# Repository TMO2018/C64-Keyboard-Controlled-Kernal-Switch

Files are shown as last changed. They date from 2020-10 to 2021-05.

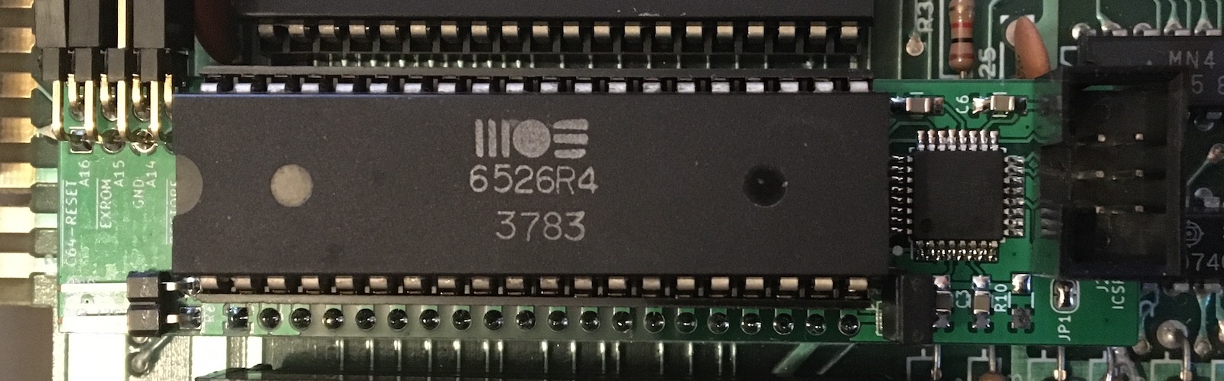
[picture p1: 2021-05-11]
Rev_3_0/pic/IMG_0387.JPG

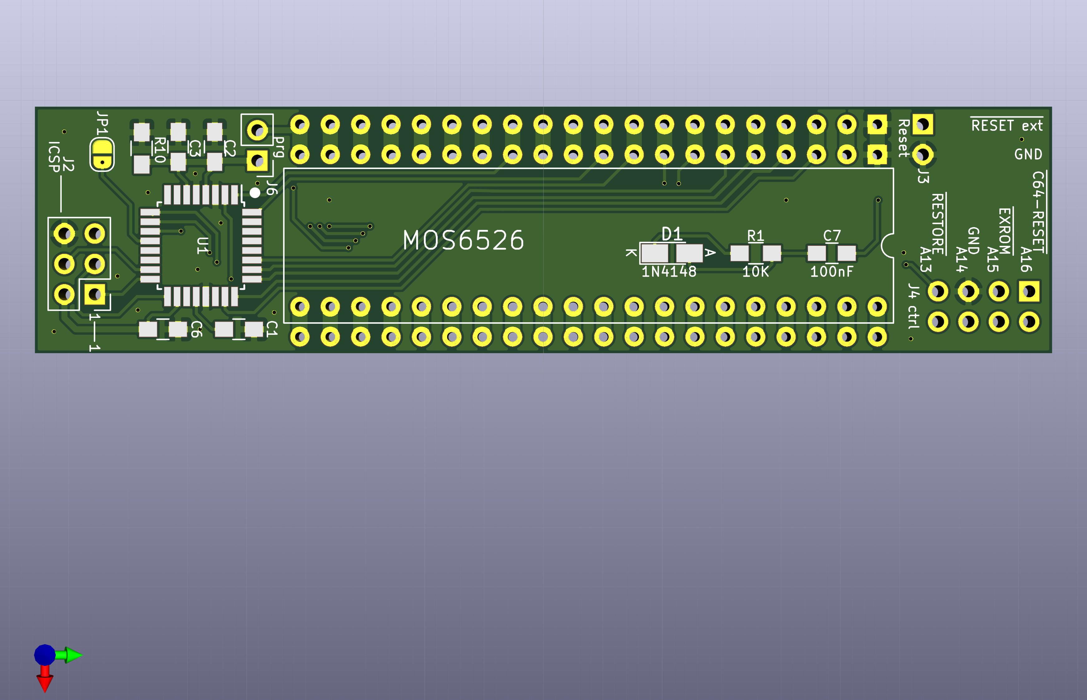
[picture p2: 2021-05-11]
Rev_3_0/pic/top.jpg

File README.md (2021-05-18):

# C64-Keyboard-Controlled-Kernal-Switch for 6526

This project is based on the C64 Keyboard Controlled Kernal Switch Rev. 1.0 from Sven Petersen  (github: svenpetersen1965). For additional informations take a look at Sven Petersens github repository. 

The original kernal switch ist directly connected to the C64 keyboard connector. In my C64 (bread box) with board Assy 250407 the Kernal Switch lies on the fastening screw and other components with the risk of an electrical connection. So I developed an alternative.
The kernal switch 6526 is an intermediate socket for the 6526 on U1.

Advantage:
- better mechanical stability
- SMD soldering pads for hand soldering

Disadvantage:
- additional line for querying the restore button
- if the 6526 is not socketed, it must be unsoldered

Rev 1.0: Design based on Sven Petersens C64 Keyboard Controlled Kernal Switch (ATmega with external clock at 16 MHz), 8 kernals

Rev 2.0: Cost-reduced Design (ATmega with internal clock at 8 MHz), 8 kernals

Rev 3.0: Expansion from 8 to 14 kernals. Based on Rev 2.0.

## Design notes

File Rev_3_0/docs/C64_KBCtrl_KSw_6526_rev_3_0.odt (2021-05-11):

Project Documentation

Commodore C64 – Keyboard Controlled Kernal Switch 6526

Revision: 3.0

Date: 24.04.2021

Cost-reduced variant, 14 kernals


C64 Keyboard Controlled Kernal Switch 6526 Rev. 3.0

General

This project is based on the C64 Keyboard Controlled Kernal Switch Rev. 1.0 from Sven Petersen (github: svenpertersen1965). For additional informations take a look at Sven Petersens github resipository.

The original kernal switch ist directly connected to the C64 keyboard connector. In my C64 (breadbin) with board Assy 250407 the Kernal Switch lies on the fastening screw and other components with the risk of an electrical connection. So I developed an alternative.

The kernal switch 6526 is an intermediate socket for the 6526 on U1.

This is an cost-reduced variant of the C64 Keyboard Controlled Kernal Switch 6526 Rev. 1.0. The ATmega runs with the internal oscillator at 8MHz. Version 3.0 dispenses with the LED and the serial debug interface. For this, the switchover from 8 to 14 kernals is being expanded.

The following components are not required: 1x crystal, 2x ceramic condensator, 4 x resistor, 1x 3 pol connector.

Advantage:

- better mechanical stability

- SMD soldering pads for hand soldering

- fewer components

Disadvantage:

- additional line for querying the restore button

- if the 6526 is not socketed, it must be unsoldered

Connection points:

RESET → Userport pin 3

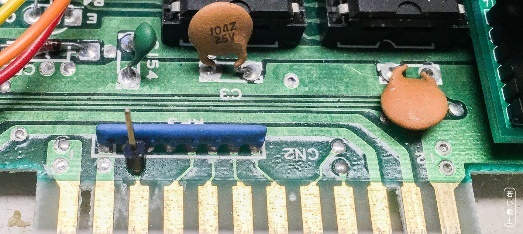
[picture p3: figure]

Figure 1: Reset Contact ASSY 250425 (identical to ASSY 250407) – Long Board

EXROM → Expansionport pin 9

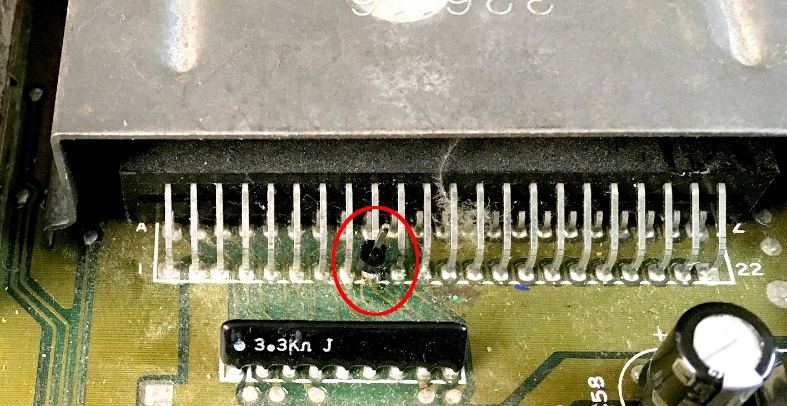
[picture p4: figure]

Figure 2: EXROM pin at the Expansion Port (Pin 9)

or

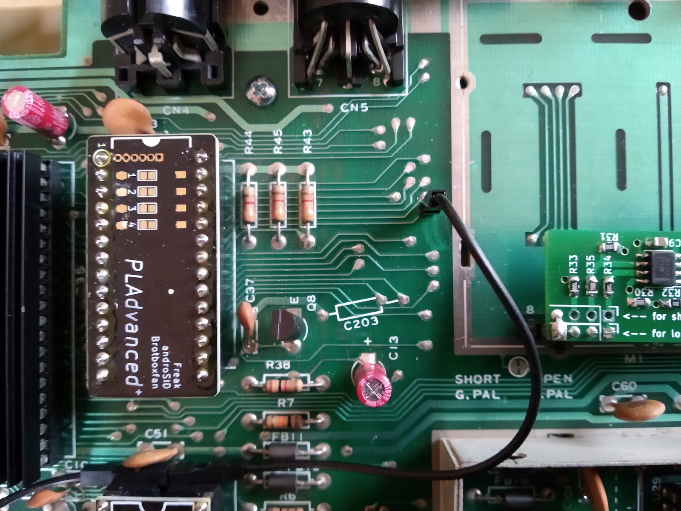
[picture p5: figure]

Figure 3: EXROM at the board 250407

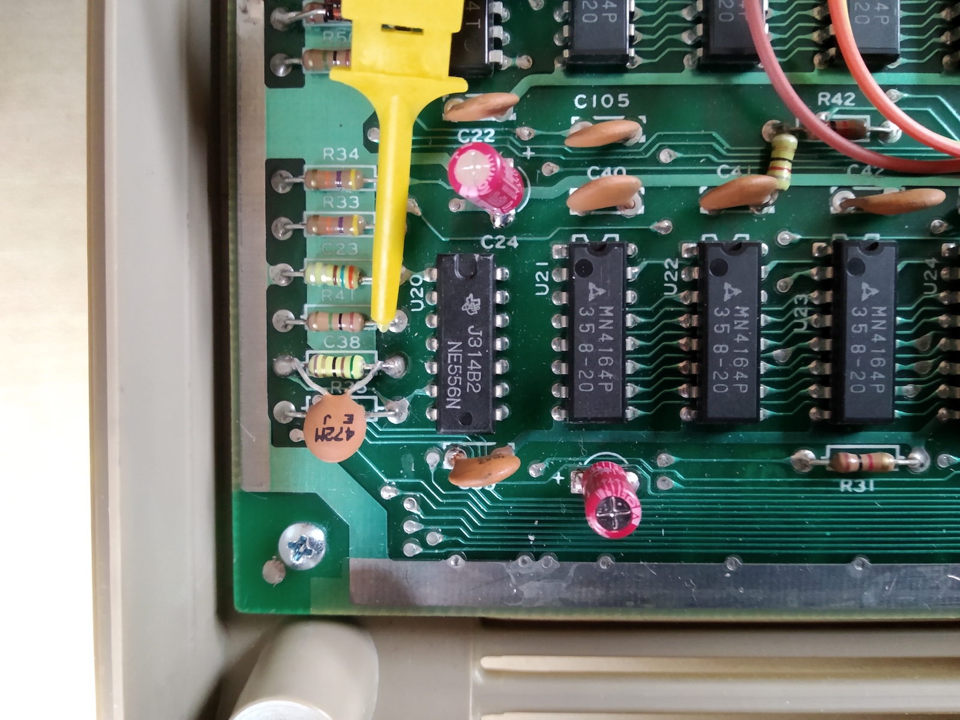
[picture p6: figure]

RESTORE → east side of R41

Figure 4: EXROM at the board 250407

Wiring of ASSY 250407. The brown cable is the reset signal, which is attached to the RESET pin header that was installed previously. The black cable is EXROM. The brown cable with the yellow clamp is RESTORE.

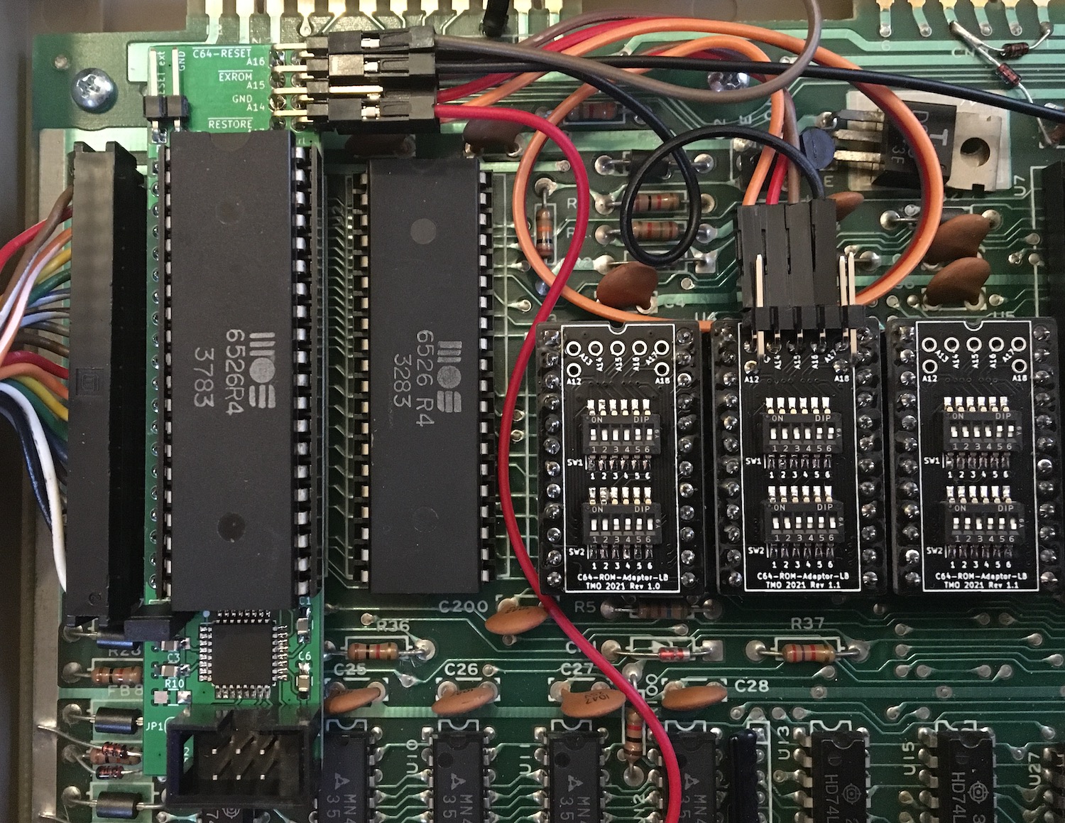
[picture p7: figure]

Figure 5: Wiring of ASSY 250407

Kernal-ROM-Selection (JP1):

JP1 open: The kernals must be in banks 1 through 14.

JP1 shorted: The basic ROM is in bank 1. The kernals must be in banks 2 through 15.

Similar to the 250469 board.

Programming:

Programm with an ISP-programmer like the Pololu USB AVR Programmer v2.1. With MacOS you can use the programm AVRfuses.

It is not necessary to remove the Kernal Switch from the C64 for programming. However, the C64 must be switched off.

For programming, the ATmega 328P must be supplied with 5V from the ISP programmer.

The programming mode is selected with J6.

J6 open → programming mode

J6 closed → kernal switch mode

Set the fuses first when programming for the first time.

Fuses:

- EXTENDED: 0xFD

- HIGH: 0xDE

- LOW: 0xE2

After that you can programm the firmware.

Firmware: c64kbksw_v0_3_basic.ino (Arduino 1.8.12)

c64kbksw_v0_3_basic.ino_atmega328p_8000000L.hex

Use only a firmware compiled für 8MHz internal clock !!!

C64_KBCtrl_KSw_6526_rev_3_0.odt Page 2 of 5 TMO doc_rev: 1.0

C64_KBCtrl_KSw_6526_rev_3_0.odt 20:59:22 Drafted by Sven Petersen Page 0 of 5 Doc.-No.: 128-6-04-00

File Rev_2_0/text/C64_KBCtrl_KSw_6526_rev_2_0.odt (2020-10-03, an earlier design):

Project Documentation

Commodore C64 – Keyboard Controlled Kernal Switch 6526

Revision: 2.0

Date: 03.10.2020

Cost-reduced variant

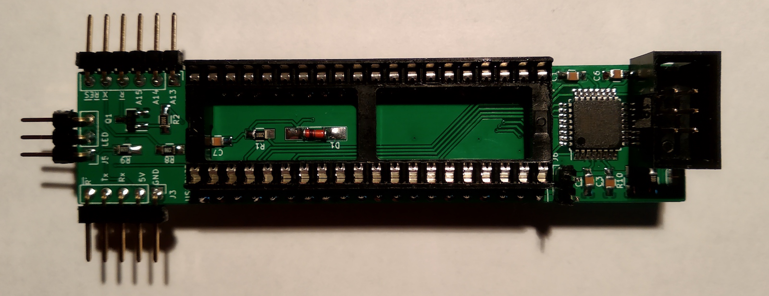
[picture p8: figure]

C64 Keyboard Controlled Kernal Switch 6526 Rev. 2.0

General

This is an cost-reduced variant of the C64 Keyboard Controlled Kernal Switch 6526 Rev. 1.0. The ATmega runs with the internal oscillator at 8MHz.

The following components are not required: 1x crystal, 2x ceramic condensator, 1 x resistor.

This project is based on the C64 Keyboard Controlled Kernal Switch Rev. 1.0 from Sven Petersen (github: svenpertersen1965). For additional informations take a look at Sven Petersens github resipository.

The original kernal switch ist directly connected to the C64 keyboard connector. In my C64 (bread box) with board Assy 250407 the Kernal Switch lies on the fastening screw and other components with the risk of an electrical connection. So I developed an alternative.

The kernal switch 6526 is an intermediate socket for the 6526 on U1.

Advantage:

- better mechanical stability

- SMD soldering pads for hand soldering

- fewer components

Disadvantage:

- additional line for querying the restore button

- if the 6526 is not socketed, it must be unsoldered

Connection points:

RESET → Userport pin 3


Figure 1: Reset Contact ASSY 250425 (identical to ASSY 250407) – Long Board

EXROM → Expansionport pin 9


Figure 2: EXROM pin at the Expansion Port (Pin 9)

or


Figure 3: EXROM at the board 250407


RESTORE → east side of R41

Figure 4: EXROM at the board 250407

Wiring of ASSY 250407. The brown cable is the reset signal, which is attached to the RESET pin header that was installed previously. The black cable is EXROM. The brown cable with the yellow clamp is RESTORE.

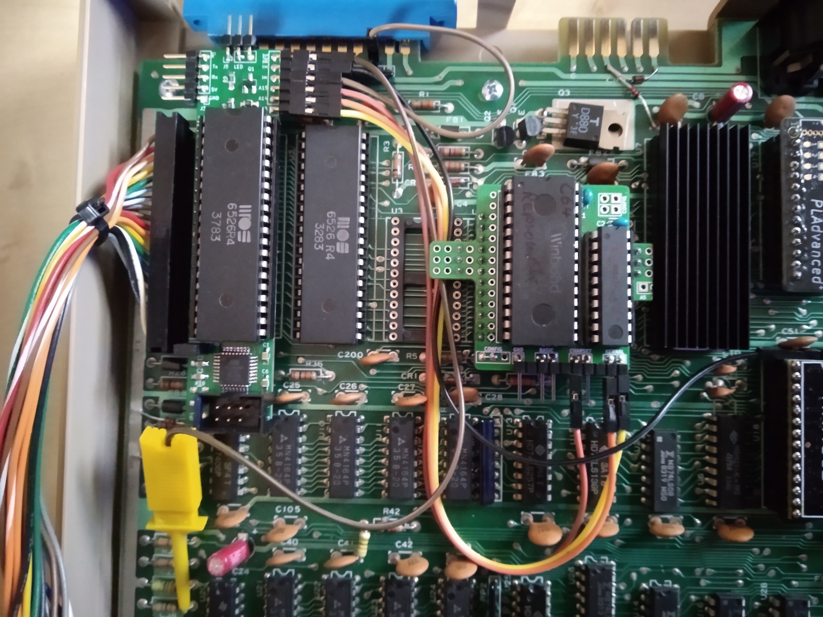
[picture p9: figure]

Figure 5: Wiring of ASSY 250407

Programming:

Programm with an ISP-programmer like the Pololu USB AVR Programmer v2.1. With MacOS you can use the programm AVRfuses.

It is not necessary to remove the Kernal Switch from the C64 for programming. However, the C64 must be switched off.

For programming, the ATmega 328P must be supplied with 5V from the ISP programmer.

The programming mode is selected with J6.

J6 open → programming mode

J6 closed → kernal switch mode

Set the fuses first when programming for the first time.

Fuses:

- EXTENDED: 0xFD

- HIGH: 0xDE

- LOW: 0xE2

After that you can programm the firmware.

Use only a firmware compiled für 8MHz internal clock !!!

C64_KBCtrl_KSw_6526_rev_2_0.odt Page 4 of 5 TMO doc_rev: 1.0

C64_KBCtrl_KSw_6526_rev_2_0.odt 18:28:27 Drafted by Sven Petersen Page 0 of 5 Doc.-No.: 128-6-04-00

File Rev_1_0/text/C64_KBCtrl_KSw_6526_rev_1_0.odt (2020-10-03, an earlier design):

Project Documentation

Commodore C64 – Keyboard Controlled Kernal Switch 6526

Revision: 1.0

Date: 03.10.2020

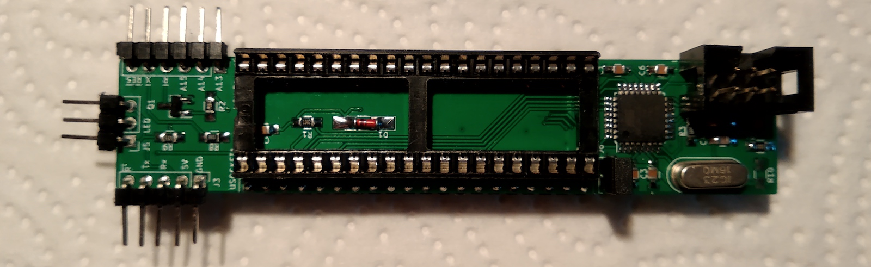
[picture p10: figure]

C64 Keyboard Controlled Kernal Switch 6526 Rev. 1.0

General

This project is based on the C64 Keyboard Controlled Kernal Switch Rev. 1.0 from Sven Petersen (github: svenpertersen1965). For additional informations take a look at Sven Petersens github resipository.

The original kernal switch ist directly connected to the C64 keyboard connector. In my C64 (bread box) with board Assy 250407 the Kernal Switch lies on the fastening screw and other components with the risk of an electrical connection. So I developed an alternative.

The kernal switch 6526 is an intermediate socket for the 6526 on U1.

Advantage:

- better mechanical stability

- SMD soldering pads for hand soldering

Disadvantage:

- additional line for querying the restore button

- if the 6526 is not socketed, it must be unsoldered

Connection points:

RESET → Userport pin 3


Figure 1: Reset Contact ASSY 250425 (identical to ASSY 250407) – Long Board

EXROM → Expansionport pin 9


Figure 2: EXROM pin at the Expansion Port (Pin 9)

or


Figure 3: EXROM at the board 250407


RESTORE → east side of R41

Figure 4: EXROM at the board 250407

Wiring of ASSY 250407. The brown cable is the reset signal, which is attached to the RESET pin header that was installed previously. The black cable is EXROM. The brown cable with the yellow clamp is RESTORE.

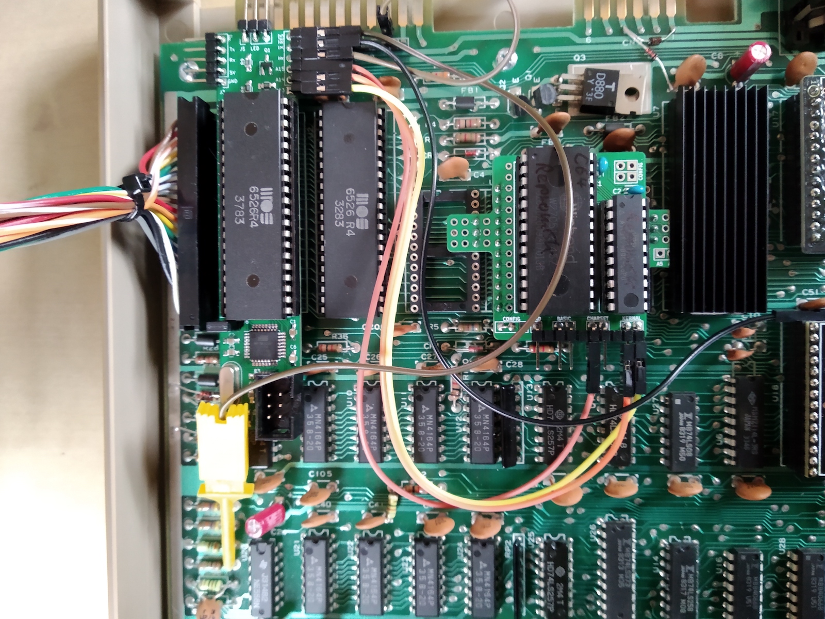
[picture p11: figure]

Figure 5: Wiring of ASSY 250407

Programming:

Programm with an ISP-programmer like the Pololu USB AVR Programmer v2.1. With MacOS you can use the programm AVRfuses.

It is not necessary to remove the Kernal Switch from the C64 for programming. However, the C64 must be switched off.

For programming, the ATmega 328P must be supplied with 5V from the ISP programmer.

The programming mode is selected with J6.

J6 open → programming mode

J6 closed → kernal switch mode

Set the fuses first when programming for the first time.

Fuses:

- EXTENDED: 0xFD

- HIGH: 0xDE

- LOW: 0xFF

After that you can programm the firmware.

C64_KBCtrl_KSw_6526.odt Page 5 of 5 TMO doc_rev: 1.0

C64_KBCtrl_KSw_6526.odt 18:04:22 Drafted by Sven Petersen Page 0 of 5 Doc.-No.: 128-6-04-00

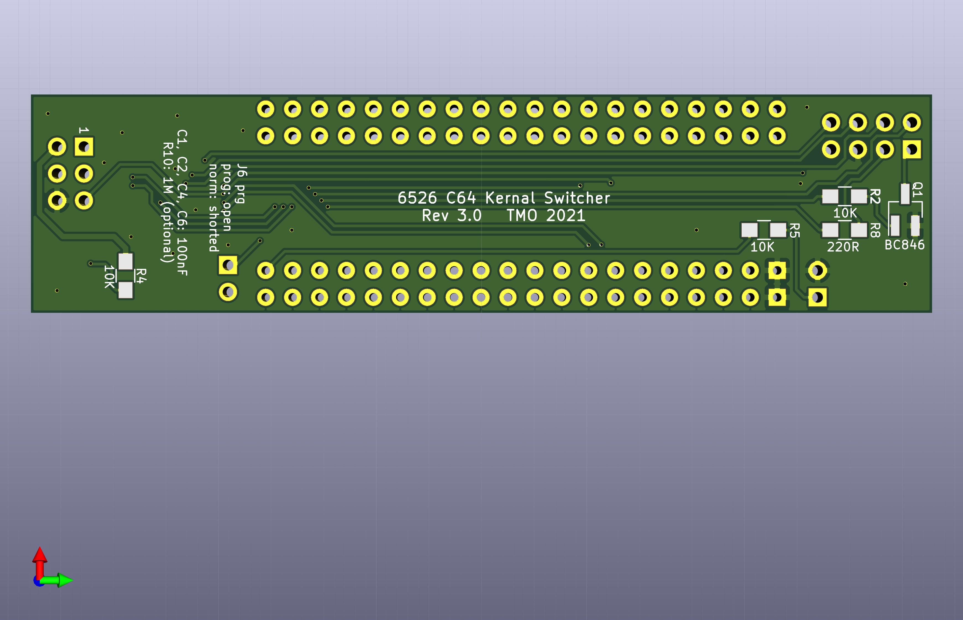
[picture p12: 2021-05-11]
Rev_3_0/pic/back.jpg

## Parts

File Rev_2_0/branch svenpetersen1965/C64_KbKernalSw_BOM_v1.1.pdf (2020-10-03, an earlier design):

C64_KbKernalSw_BOM_v1.1.xlsx
Drafted by Sven Petersen | Page 1 of 1

03.10.2020 18:42:13
Doc.No.: 128-5-01-01.1

## C64 Keyboard Controlled Kernal Switch Rev. 1 Bill of Material Rev. 1.1

Pos. | Qty Value | Footprint | Ref.-No. | Comment
1 | 1 128-2-01-01 | 2 Layer | PCB Rev. 1 | 2 layer, Cu 35µ, HASL, 101.2mm x 20.0mm, 1.6mm FR4
2 | copper structure on pcb | | CP1 | no part, open Cutpad, close for ASSY250469
3 | 1 1x20 | 1X20 | J5 | pin header 1x20pin, 2.54mm pitch
4 | 1 1x7 | 1X07 | J4 | pin header 1x7pin, 2.54mm pitch
5 | 5 100n | 0805 | C1, C2, C3, C6, C7 | SMD capacitor
6 | 4 10k | 0805 | R1, R2, R4, R5 | SMD resistor, 5% or better
7 | 1 1M | 0805 | R3 | SMD resistor, 5% or better
8 | 2 1k | 0805 | R6, R7 | SMD resistor, 5% or better
9 | 2 22p | 0805 | C4, C5 | SMD capacitor
10 | 1 ATMEGA328P-AU | | IC1 | Atmel/Micro Chip, e.g. Farnell 2443176
11 | 1 BC846B | SOT23 | Q1 | SMD transistor
12 | 1 16 MHz/20pF quarz | HC49SLF | X1 | e.g. Fox Electronics, FOXSLF/160-20, Farnell 2063950
13 | 1 LL4148 | SOD80C | D1 | SMD diode
14 | 1 M20-7862042 | M20-7862042 | J1 | Harwin, e.g. Farnell 1256661
15 | 1 WSL 6G | 2X03WV | J2 | box pin header, 2x3pin, 2.54mm pitch
16 | 1 1x5 | 1X05 | J3 | pin header 1x5pin, 2.54mm pitch
17 | 1 220R | 0805 | R8 | SMD resistor, 5% or better
18 | 1 330R | 0805 | R9 | SMD resistor, 5% or better
19 | 1 n/a | 0805 | R10 | not placed
| Rev. History
Pos. | Rev. 0 -> Rev. 1.1
1 | PCB revision
4 | Now 7 pin
17 | new
18 | new
19 | new

QFP80P900X90
0X120-32N

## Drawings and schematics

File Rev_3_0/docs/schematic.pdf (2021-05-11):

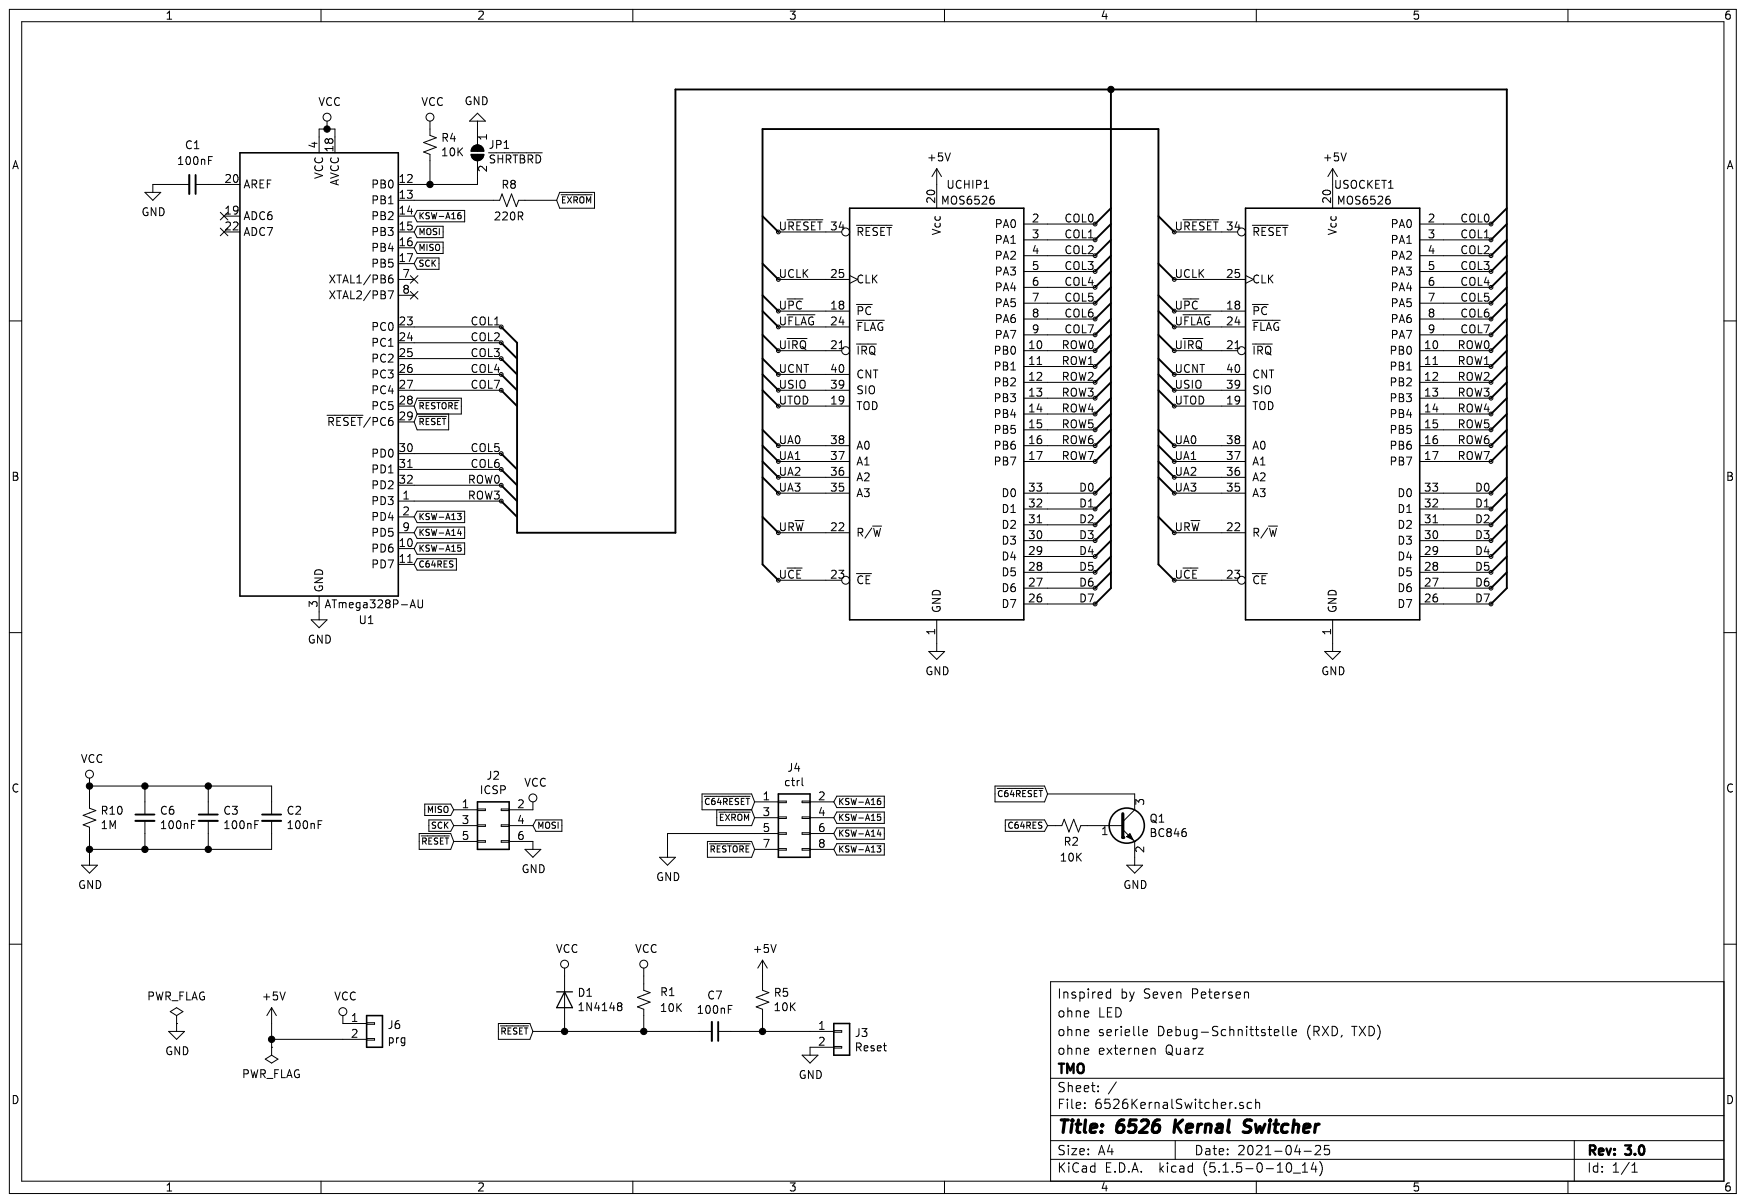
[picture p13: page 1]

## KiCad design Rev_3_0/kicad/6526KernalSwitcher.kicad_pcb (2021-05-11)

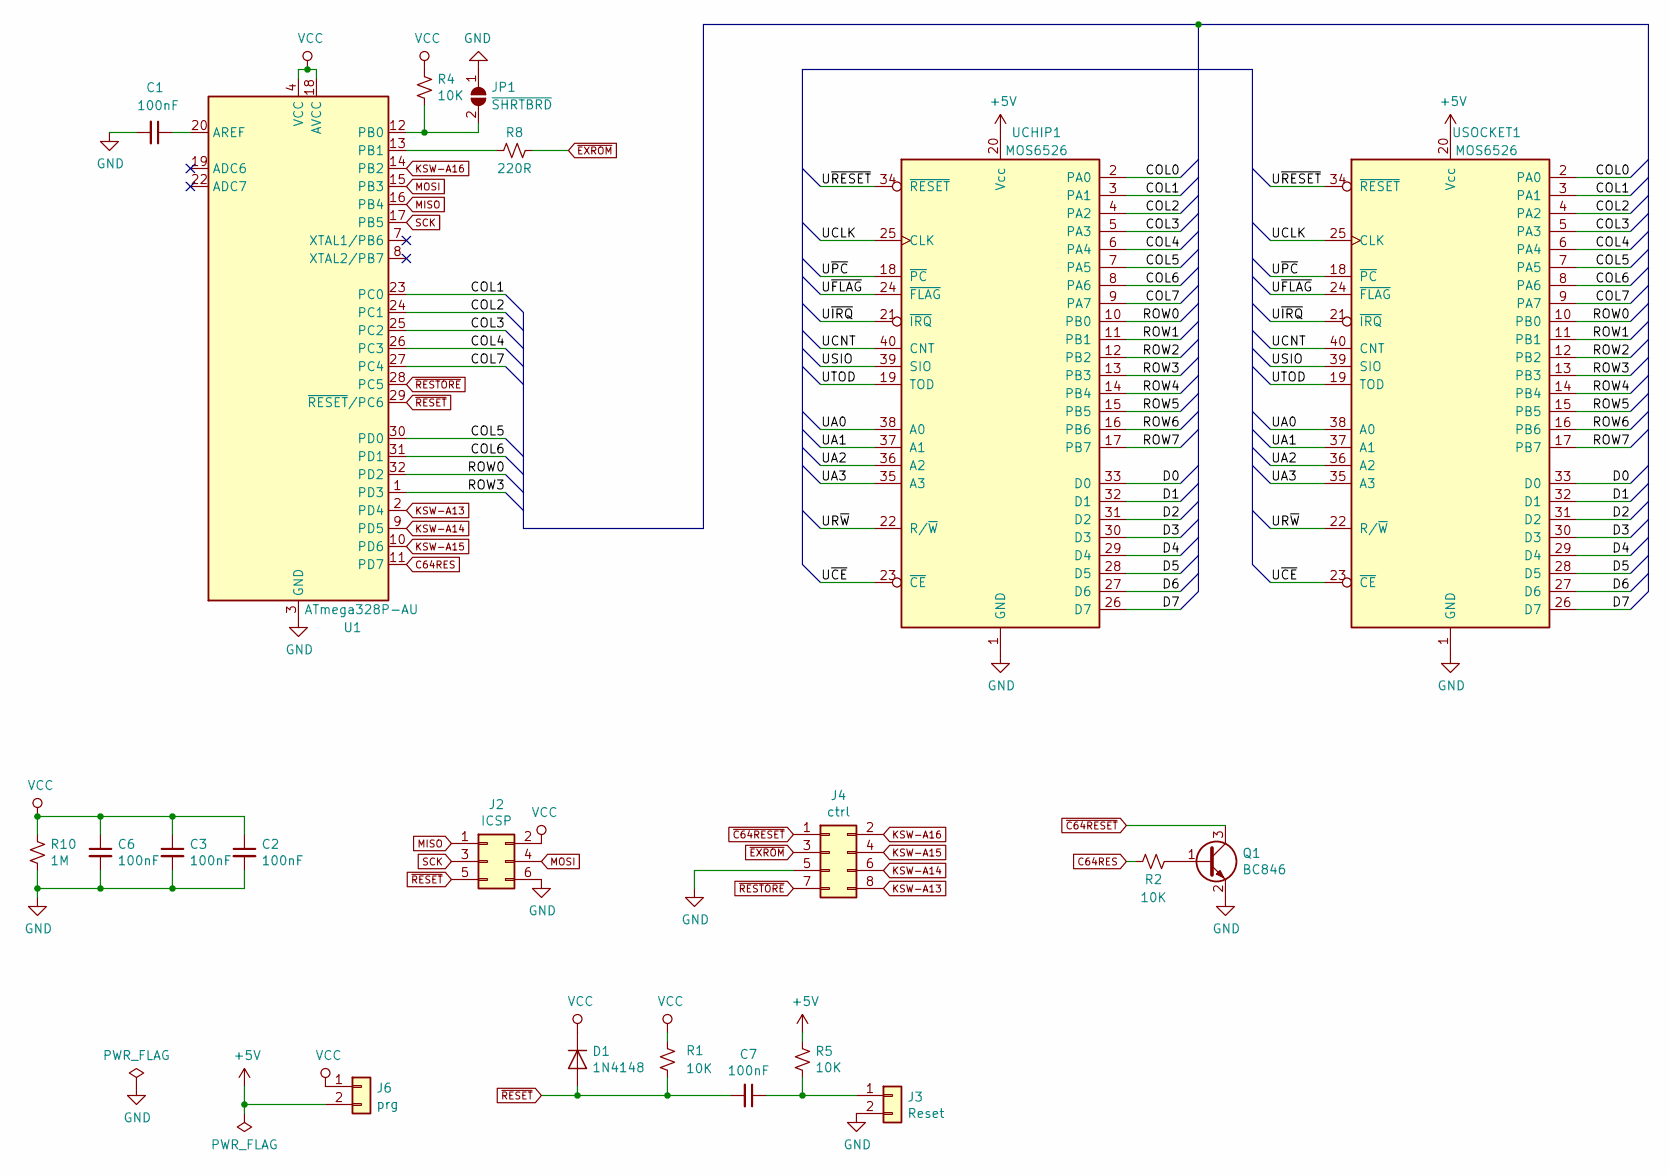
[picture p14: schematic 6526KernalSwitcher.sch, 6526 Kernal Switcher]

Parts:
C1, C2, C3, C6, C7: 100nF; C_0805_HandSoldering
D1: 1N4148; D_MicroMELF_Hadsoldering
J2: ICSP; Pin_Header_Straight_2x03_Pitch2.54mm
J3: Reset; Pin_Header_Angled_1x02_Pitch2.54mm_no_silk
J4: ctrl; Pin_Header_Angled_2x04_Pitch2.54mm_no_silk
J6: prg; Pin_Header_Straight_1x02_Pitch2.54mm
JP1: ~SHRTBRD; SolderJumper-2_P1.3mm_Open_RoundedPad1.0x1.5mm
Q1: BC846; SOT-23_Handsoldering
R1, R2, R4, R5: 10K; R_0805_HandSoldering
R8: 220R; R_0805_HandSoldering
R10: 1M; R_0805_HandSoldering
U1: ATmega328P-AU; TQFP-32_7x7mm_Pitch0.8mm
UCHIP1: MOS6526; DIP-40_W15.24mm
USOCKET1: MOS6526; DIP-40_W15.24mm_Pin_Rows_TMO

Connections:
+5V: J6.2, R5.1, UCHIP1.20 (Vcc), USOCKET1.20 (Vcc)
/COL0: UCHIP1.2 (PA0), USOCKET1.2 (PA0)
/COL1: U1.23 (PC0), UCHIP1.3 (PA1), USOCKET1.3 (PA1)
/COL2: U1.24 (PC1), UCHIP1.4 (PA2), USOCKET1.4 (PA2)
/COL3: U1.25 (PC2), UCHIP1.5 (PA3), USOCKET1.5 (PA3)
/COL4: U1.26 (PC3), UCHIP1.6 (PA4), USOCKET1.6 (PA4)
/COL5: U1.30 (PD0), UCHIP1.7 (PA5), USOCKET1.7 (PA5)
/COL6: U1.31 (PD1), UCHIP1.8 (PA6), USOCKET1.8 (PA6)
/COL7: U1.27 (PC4), UCHIP1.9 (PA7), USOCKET1.9 (PA7)
/D0: UCHIP1.33 (D0), USOCKET1.33 (D0)
/D1: UCHIP1.32 (D1), USOCKET1.32 (D1)
/D2: UCHIP1.31 (D2), USOCKET1.31 (D2)
/D3: UCHIP1.30 (D3), USOCKET1.30 (D3)
/D4: UCHIP1.29 (D4), USOCKET1.29 (D4)
/D5: UCHIP1.28 (D5), USOCKET1.28 (D5)
/D6: UCHIP1.27 (D6), USOCKET1.27 (D6)
/D7: UCHIP1.26 (D7), USOCKET1.26 (D7)
/ROW0: U1.32 (PD2), UCHIP1.10 (PB0), USOCKET1.10 (PB0)
/ROW1: UCHIP1.11 (PB1), USOCKET1.11 (PB1)
/ROW2: UCHIP1.12 (PB2), USOCKET1.12 (PB2)
/ROW3: U1.1 (PD3), UCHIP1.13 (PB3), USOCKET1.13 (PB3)
/ROW4: UCHIP1.14 (PB4), USOCKET1.14 (PB4)
/ROW5: UCHIP1.15 (PB5), USOCKET1.15 (PB5)
/ROW6: UCHIP1.16 (PB6), USOCKET1.16 (PB6)
/ROW7: UCHIP1.17 (PB7), USOCKET1.17 (PB7)
/UA0: UCHIP1.38 (A0), USOCKET1.38 (A0)
/UA1: UCHIP1.37 (A1), USOCKET1.37 (A1)
/UA2: UCHIP1.36 (A2), USOCKET1.36 (A2)
/UA3: UCHIP1.35 (A3), USOCKET1.35 (A3)
/UCLK: UCHIP1.25 (CLK), USOCKET1.25 (CLK)
/UCNT: UCHIP1.40 (CNT), USOCKET1.40 (CNT)
/UR~W: UCHIP1.22 (R/~W~), USOCKET1.22 (R/~W~)
/USIO: UCHIP1.39 (SIO), USOCKET1.39 (SIO)
/UTOD: UCHIP1.19 (TOD), USOCKET1.19 (TOD)
/U~CE: UCHIP1.23 (~CE~), USOCKET1.23 (~CE~)
/U~FLAG: UCHIP1.24 (~FLAG~), USOCKET1.24 (~FLAG~)
/U~IRQ: UCHIP1.21 (~IRQ~), USOCKET1.21 (~IRQ~)
/U~PC: UCHIP1.18 (~PC~), USOCKET1.18 (~PC~)
/U~RESET: UCHIP1.34 (~RESET~), USOCKET1.34 (~RESET~)
C64RES: R2.2, U1.11 (PD7)
GND: C1.2, C2.2, C3.2, C6.2, J2.6, J3.2, J4.5, JP1.1 (A), Q1.2 (E), R10.2, U1.3 (GND), U1.5 (GND), U1.21 (GND), UCHIP1.1 (GND), USOCKET1.1 (GND)
KSW-A13: J4.8, U1.2 (PD4)
KSW-A14: J4.6, U1.9 (PD5)
KSW-A15: J4.4, U1.10 (PD6)
KSW-A16: J4.2, U1.14 (PB2)
MISO: J2.1, U1.16 (PB4)
MOSI: J2.4, U1.15 (PB3)
unnamed: C1.1, U1.20 (AREF)
unnamed: C7.1, J3.1, R5.2
unnamed: JP1.2 (B), R4.2, U1.12 (PB0)
unnamed: Q1.1 (B), R2.1
unnamed: R8.2, U1.13 (PB1)
SCK: J2.3, U1.17 (PB5)
VCC: C2.1, C3.1, C6.1, D1.1 (K), J2.2, J6.1, R1.1, R4.1, R10.1, U1.4 (VCC), U1.6 (VCC), U1.18 (AVCC)
~C64RESET: J4.1, Q1.3 (C)
~EXROM: J4.3, R8.1
~RESET: C7.2, D1.2 (A), J2.5, R1.2, U1.29 (~RESET~/PC6)
~RESTORE: J4.7, U1.28 (PC5)

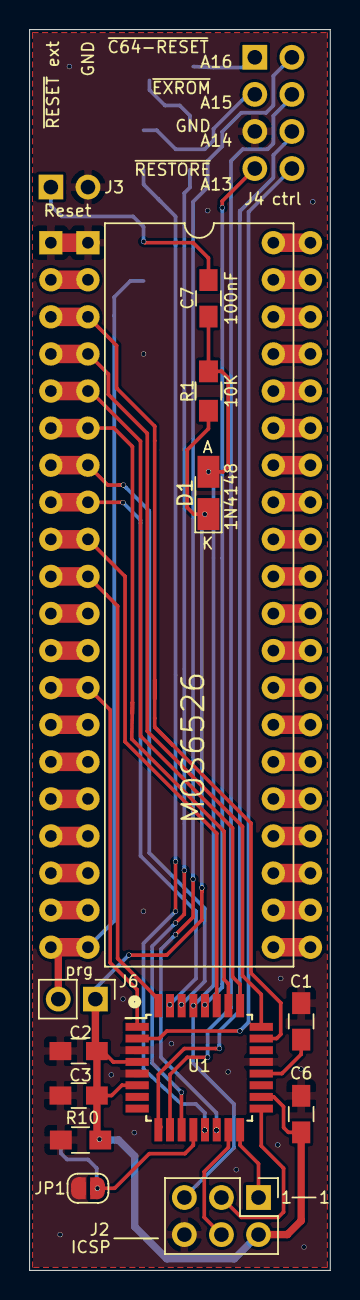
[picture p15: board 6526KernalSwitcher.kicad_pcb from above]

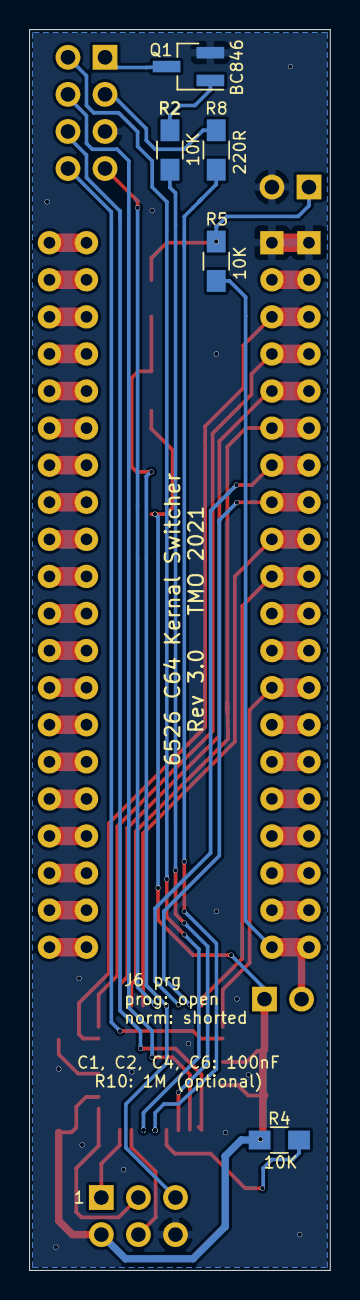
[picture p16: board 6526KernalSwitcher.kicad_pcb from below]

Board: 2 copper layers, 20.6 x 85.0 mm, 21 parts (5 on the bottom side), 58 nets.

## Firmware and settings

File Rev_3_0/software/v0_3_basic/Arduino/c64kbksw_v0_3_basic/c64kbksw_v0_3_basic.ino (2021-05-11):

/*  Software for the keyboard controlled kernal switch
 *  by Sven Petersen, 2020
 *  
 *  Revisioon history 
 *  Rev. 0.0: initial release
 *  Rev. 0.1: since some games (e.g. Gyruss) modify the reset procedure, the "unstoppable reset" (= EXROM Reset) was 
 *            implemented. Pressing RESTORE for approximatety 2-4 seconds is a normal reset, holding it longer =  
 *            EXROM reset.
 *  Rev. 0.2: Implemented signalling on RESIO2.          
 *  Rev. 0.3: Expansion from 8 to 14 kernals, no bootloader, no RX, TX (TMO)
 *  Rev. 0.3_basic: Expansion from 8 to 14 kernals, no bootloader, no RX, TX (TMO), Basic in first bank
 */

#define LED
//#define buzzer

#include <EEPROM.h>

/* Configuration */
const bool recover_empty = true;     //enable recover to Kernal one, in case an empty/not working kernal was selected
//TMO: const int  NumKernal = 8;            //This is the highest valid Kernal number
const int  NumKernal = 14;            //This is the highest valid Kernal number
 
/* pin definitions */
const int row0 = 2;         // Row signal, input, active low, INT0
const int row3 = 3;         // Row signal, input, active low, INT1
const int KSW_A13 = 4;      // output, A13 to kernal adaptor/switch
const int KSW_A14 = 5;      // output, A14 to kernal adaptor/switch
const int KSW_A15 = 6;      // output, A15 to kernal adaptor/switch
const int C64RESET = 7;     // output, RESET signal for the C64
const int col1 = A0;        // input, column signal, active low
const int col2 = A1;        // input, column signal, active low
const int col3 = A2;        // input, column signal, active low
const int col4 = A3;        // input, column signal, active low
const int col5 = 0;        //TNO: input, column signal, active low
const int col6 = 1;        //TMO: input, column signal, active low
const int col7 = A4;        // input, column signal, active low
const int nRESTORE = A5;    // input, RESTORE key, active low
const int nSHORT_BRD = 8;   // input, short board jumper
const int nEXROM = 9;       // /EXROM Pin connected to pin header J4, pin 5 
// const int RSVD = 10;    // reserved. Pin connected to pin header J4, pin 6
//TMO: const int Signalling = 10; // Pin for signaling (LED or buzzer with tone generator), pin header J4, pin 6
const int KSW_A16 = 10; // TMO: output, A17 to kernal adaptor/switch

#ifdef buzzer
const bool sig_idle = LOW;   // idle level of J4, pin 6 (should be HIGH for a power LED) 
#else
const bool sig_idle = HIGH;  // idle level of J4, pin 6 (should be HIGH for a power LED)
#endif 

const int Restore_Count = 1500; // count appr. 2 seconds for RestoreKey before Reset
const int EXROM_Count = 3000;   // limit for EXROM reset
const int Sig_time = 500; // constant for signalling duration

/* other constants */
#define EEPROMAddr 0        // EEPROM Address of last kernal selection
#define ScanDelay 10000     // delay ibn ms before reset for no scan activity or an empty kernal memory slot, respectively

/* variables */
byte KOffset = 0;           // offset for kernal number
byte KNumber = 0;           // Kernal number
byte KAddr = 0;             // Address bits for Kernal
bool RestoreKey = 0;        // holds the info, if the restore key is pressed 
bool oldRestoreKey = 0;     // remeber the old status to compare
int  countup = 0;           // counter for restore key time measurement
byte key = 128;             // calculate the Key
int  KMax;                  // holds the highest Kernal Number


/* Data Exchange variables for ISR (have to be volatile) */
volatile bool NumPressed = 0;  // ISR flag for number pressed
volatile bool NumOdd = 0;      // ISR flag for odd numbers. Row0 => odd numbers, Row3 => even numbers
//TMO volatile byte ColData = 0x1F;  // column data, read from PORTC
volatile byte ColData = 0x7F;  // column data, read from PORTC and PORTD

/* in case, the kernal switch switches to a memory slot without a proper kernal software
 *  there is no keyboard scan activity. That is why the kernal switch cannot detect keys anymore
 *  to circumvent this, the column scan activity is detected. If there is no activity after switching kernals
 *  the kernal is set to #1 and the C64 is reset.
 */
byte columns;           // variable for reading out the column
int scan_cnt;           // 5000 miliseconds without scan changing to kernal #1 and resetting
int scan_found;         // flag for keybioard activity detected
byte inactive = 0;      // keyboard scan inactive: 1 -> inactive, 0 = active
bool exrom_mode = 0;    // exrom reset: 0 => no, 1 => yes
int signalling_cnt = 0; // count down for signalling pin

void setup() {
  /* keyboard scan signals */
  pinMode( row0, INPUT_PULLUP);  // pullup required for MOS logic
  pinMode( row3, INPUT_PULLUP);  // pullup required for MOS logic
  pinMode( col1, INPUT_PULLUP);  // pullup required for MOS logic
  pinMode( col2, INPUT_PULLUP);  // pullup required for MOS logic
  pinMode( col3, INPUT_PULLUP);  // pullup required for MOS logic
  pinMode( col4, INPUT_PULLUP);  // pullup required for MOS logic
  pinMode( col5, INPUT_PULLUP);  //TMO: pullup required for MOS logic
  pinMode( col6, INPUT_PULLUP);  //TMO: pullup required for MOS logic
  pinMode( col7, INPUT_PULLUP);  // pullup required for MOS logic
  pinMode( nRESTORE, INPUT_PULLUP);  // pullup required for MOS logic
  pinMode( nEXROM, INPUT );      // it needs to be high impedance, will switch to LOW and OUTPUT when required.
  digitalWrite( nEXROM, HIGH );
//TMO:  digitalWrite( Signalling, sig_idle ); // Signalling pin6, J4
//TMO:  pinMode( Signalling, OUTPUT);

  /* jumper */
  pinMode(nSHORT_BRD, INPUT);   // jumper: LOW = Short Board => lowest kernal number is 1
  if (digitalRead(nSHORT_BRD) == LOW)
  { 
    KOffset = 1; // it is a short board! kernal number offset is 1, since the BASIC is in the lowest 8k of the Kernal ROM
  }

  /* last kernal from eeprom */
  KNumber = EEPROM.read(EEPROMAddr);
//TMO:  if ((KNumber < 1) || (KNumber > 8-KOffset)) { // if out of range, the first kernal is selected.
  if ((KNumber < 1) || (KNumber > NumKernal)) { // if out of range, the first kernal is selected.
    KNumber = 1;
    EEPROM.write(EEPROMAddr, KNumber);
  }
  inactive = EEPROM.read(EEPROMAddr+1);         // keyscan inactive flag
  if (inactive > 1) {
    inactive = 0;
    EEPROM.write(EEPROMAddr+1, inactive);
  }
  exrom_mode = 0;                               // initialize exrom mode (for reset). 0 = no exrom reset
  
  KAddr = KNumber - 1 + KOffset; // Calculate the address bits.
  // For long boards, it should be between 0 and 7,
  // for short boards, it should be 1 to 7, because the first 8k are occupied by the BASIC ROM. 
  //TMO: For long boards, it should be between 0 and 13,
  //TMO: for short boards, it should be 1 to 14, because the first 8k are occupied by the BASIC ROM.
  
  /* Control outputs (for Kernal Adaptor and C64) */
  SetAddressBits( KAddr );        // set the MS address bits for the kernal ROM
  pinMode( KSW_A13, OUTPUT );     // make it an output   
  pinMode( KSW_A14, OUTPUT );     // make it an output
  pinMode( KSW_A15, OUTPUT );     // make it an output
  pinMode( KSW_A16, OUTPUT );     // TMO: make it an output   
  digitalWrite( C64RESET, LOW );  // no reset for the C64
  pinMode( C64RESET, OUTPUT );    // make it an output

  if (recover_empty == true) {
    scan_cnt = ScanDelay;         // reset scan countdown
    scan_found = false;           // reset detection flag 
 //TMO:   KMax = 8 - KOffset; 
 //TMO:   KMax = NumKernal - KOffset;
    KMax = NumKernal;
  }
  else {
    scan_cnt = 0;                 // reset scan countdown
    scan_found = true;            // reset detection flag
    KMax = NumKernal;
  }
  if (inactive == 1) {             // if scan timeout is inactive, just set scan_found
    scan_found = true;
    scan_cnt = 0;
  }  
  attachInterrupt(digitalPinToInterrupt(row0), ISR_row0, LOW); 
  attachInterrupt(digitalPinToInterrupt(row3), ISR_row3, LOW);

/*TMO:  Serial.begin(9600);  // start serial interface
  /* output status etc. */
/*TMO:  Serial.println( "\nC64 Keyboard Controlled Kernal Switch v0.20" );
  if (KOffset == 1) {
    Serial.println("Short Board configured.");
  }
  else {
    Serial.println("Long Board configured.");
  }
  if (recover_empty == true) {
    Serial.print("Empty Kernal slot (=scan activity) detection: ");
    if (inactive == 1 ) {
      Serial.println("inactive.");
    }
    else {
      Serial.println("active.");
    }
  }
  else {
    Serial.print("Number of Kernals: ");
    Serial.println(NumKernal);
  }
  Serial.print("Kernal number: ");
  Serial.println( KNumber ); */
} 

/* This function sets the address bits on the pin header J4. Parameter is addr (0..7) */
void SetAddressBits( byte addr ) {
   digitalWrite( C64RESET, HIGH );                              // do it, while /reset is low (samle like the port pin is high)
   delay (50 );                                                 // wait 50 ms
   if ((addr & 1) == 0) {         // A13                  
    digitalWrite(KSW_A13, LOW);
  }
  else {
    digitalWrite(KSW_A13, HIGH);  
  }
  if ((addr & 2) == 0) {          // A14
    digitalWrite(KSW_A14, LOW);
  }
  else {
    digitalWrite(KSW_A14, HIGH);  
  }
  if ((addr & 4) == 0) {          // A15
    digitalWrite(KSW_A15, LOW);
  }
  else {
    digitalWrite(KSW_A15, HIGH);  
  } 
  if ((addr & 8) == 0) {          //TMO: A16
    digitalWrite(KSW_A16, LOW);   //TMO
  }                               //TMO
  else {                          //TMO
    digitalWrite(KSW_A16, HIGH);  //TMO 
  }                               //TMO
}

void ResetC64() {
//TMO:  digitalWrite( Signalling, !sig_idle );                     // Signalling active
  digitalWrite( C64RESET, HIGH );                            // issue a reset pulse for the C64
  delay( 100 );                                              // 100ms delay
  if (exrom_mode == 1) {
    digitalWrite( nEXROM, LOW );                             // exrom pin low
    pinMode( nEXROM, OUTPUT );                               // and output
  }
  delay( 300 );                                              // pulse duration: 100+300ms
  digitalWrite( C64RESET, LOW );
  if (exrom_mode == 1) {
    delay( 300 );                                            // EXROM should be 300ms longer LOW than RESET
    pinMode( nEXROM, INPUT );                                // and input = high impedance (HIZ)
    digitalWrite( nEXROM, HIGH );                            // exrom pin high
  }
  if ((recover_empty == true) && (inactive == 0)) {
    scan_cnt = ScanDelay;                                    // reset scan countdown
    scan_found = false;                                      // reset detection flag
  }  
  else {
    scan_cnt = 0;
    scan_found = true;
  }
  countup = 0;
//TMO:  digitalWrite( Signalling, sig_idle );                      // Signalling inactive
}

void SwitchKernal() {
  digitalWrite( C64RESET, HIGH );                            // issue a reset pulse for the C64
  SetAddressBits( KAddr );                                   // set the address bits A16..A13
//TMO:  Serial.print("Change to Kernal number: ");                 // send the status to serial
//TMO:  Serial.println( KNumber );
  ResetC64();                                                // Reset the C64
  delay( 2000 );                                             // give some delay to release the RESTORE key
}

// Interrupt Service Routine for Row0
void ISR_row0() {
  if (NumPressed == 0) {                  // only process info, after the flag was reset by main routine
//TMO:    ColData = PINC & 0x1F;               // read the columns
     ColData = (PINC & 0x1F) | ((PIND & 0x03) << 5);       //TMO: read the columns, PIND bitshift um 5 nach links
     scan_found = true;                   // any activity here indicates a working kernal
     NumOdd = 1;                          // row0 has the odd numbers
//TMO:     if ((ColData != 0x1F) && (ColData !=0)) {               // only set the flag, when a number is pressed 
     if ((ColData != 0x7F) && (ColData !=0)) {               //TMO: only set the flag, when a number is pressed
       NumPressed = 1;
     }  
  }
}

// Interrupt Service Routine for Row3
void ISR_row3 () {
  if (NumPressed == 0) {                  // only process info, after the flag was reset by main routine
//TMO:    ColData = PINC & 0x1F;               // read the columns
     ColData = (PINC & 0x1F) | ((PIND & 0x03) << 5);        //TMO: read the columns, PIND bitshift um 5 nach links
     scan_found = true;                   // any activity here indicates a working kernal
     NumOdd = 0;                          // row3 has the even numbers
//TMO:      if ((ColData != 0x1F) && (ColData !=0)) { // only set the flag, when a number is pressed 
     if ((ColData != 0x7F) && (ColData !=0)) {               //TMO: only set the flag, when a number is pressed
       NumPressed = 1;
     }  
  }
}

void loop() {
  /* find the scan activity to make sure, the selected Kernal is working */
  if (scan_found == false) {                            // if not yet a scan activity is detected
//TMO:     columns = PINC & 0x1F;                              // read the column data
     columns = (PINC & 0x1F) | ((PIND & 0x03) << 5);     //TMO: read the column data
//TMO:    if ((columns != 0x1F)) {                            // activity found?
    if ((columns != 0x7F)) {                            //TMO: activity found?
      scan_found = true;                                // set flag
//TMO:      Serial.println( "Keyboard scan detected."); 
    }
    else {
      if (scan_cnt > 0) {                               // if the count down is not elapsed
        scan_cnt--;                                     // then decrement
        delayMicroseconds( 33 );
      }
      else {
//TMO:        Serial.println( "No keyboard scan detected.");  // the count down is elapsed!
        KNumber = 1;                                    // Set Kernal Number 1 (it is assumed, that this is not empty)
        EEPROM.write(EEPROMAddr, KNumber);              // and save in EEPROM
        KAddr = KOffset;                                // Calculate the address bits.
        SwitchKernal();                                 // Switch Kernal Number and reset C64
      }
    }
  }
  
  /* process restore key */ 
  if (digitalRead( nRESTORE ) == HIGH) {
     if (RestoreKey == 1) {                // now no RESTORE, but last status was RESTORE => Restore key released 
        if (countup > EXROM_Count) {       // is the limit for EXROM reset reached?
          exrom_mode = 1;
//TMO:          Serial.print( "EXROM mode: ");
        }
        if (countup > Restore_Count) {
//TMO:          Serial.println("Restore key => Reseting the C64");
          ResetC64();                      // RESET the C64
          exrom_mode = 0;
        }
     }
     RestoreKey = 0;                      // in case the reading is HIGH, the Restore key is not pressed
     countup = 0;                         // restart the count down
  }
  else {
    RestoreKey = 1;                       // in case the restore is pressed, count up
    countup++;
    if (countup == Restore_Count ) {
//TMO:        digitalWrite( Signalling, !sig_idle );
       signalling_cnt = Sig_time;
    }
    if (countup > EXROM_Count) {          // time limit for EXROM reached?
       exrom_mode = 1;                    // activate EXROM mode
//TMO:       Serial.println("EXROM mode: Restore key => Reseting the C64");
       ResetC64();                        // reset the C64
       RestoreKey = 0;                    // restart the restore key
       countup = 0;                       // restart the count down
       exrom_mode = 0;                    // reset EXROM mode
    }
  }
  if (signalling_cnt > 0) {
    if (--signalling_cnt == 0) {
//TMO:      digitalWrite( Signalling, sig_idle );
    }
  }
  /* The ISR will set NumPressed to 1, in case some number key is pressed 
     In case something is found, the column data, which was read by the ISR 
     is being processed here.  
  */
  if (NumPressed == 1) {                     // if a number key is pressed: process the data
    if ((ColData & B00010000) == 0) {        // column 7: "1"
      key = 1;
    }
    else if ((ColData & B00000001) == 0) {   // column 1: "3"
      key = 3;
    }
    else if ((ColData & B00000010) == 0) {   // column 2: "5"
      key = 5;
    }
    else if ((ColData & B00000100) == 0) {   // column 3: "7"
      key = 7;
    }
    else if ((ColData & B00001000) == 0) {   // column 4: "9"
      key = 9;
    }
    else if ((ColData & B00100000) == 0) {   // column 5: "+"        //TMO key "+" (11)
      key = 11;                                                      //TMO
    }                                                                //TMO
    else if ((ColData & B01000000) == 0) {   // column 6: "Pfund"    //TMO key "Pfund" (13)
      key = 13;                                                      //TMO
    }                                                                //TMO
    /*
     * The even numbers are on row 3, the odd numbers are on row 1
     * NumOdd is set by the ISR
    */
    if (NumOdd == 0) {                       // the even number are higher by one
      key++;
    }
//TMO:    if (key == 10) {                         // in case it is a "0" 
//TMO:      key = 0;
//TMO:    }

//TMO:    Serial.print("Key ");
//TMO:    Serial.print(key);
//TMO:    Serial.println(" detected.");
    if ((key > 0) && (key < KMax+1) && (RestoreKey == 1)) {       // restore pressed and key in range
       KNumber = key;                                             // set Kernal Number
       EEPROM.write(EEPROMAddr, KNumber);                         // write it to the EEPROM
//TMO:       KAddr = KNumber - 1 + KOffset;                             // Calculate the address bits. 
                                                                  // For long boards, it should be between 0 and 7,
                                                                  // for short boards, it should be 1 to 7, because the first 8k are occupied by the BASIC ROM. 
       if (KOffset == 0)                                          //TMO
          KAddr = KNumber - 1;                                    //TMO
       else                                                       //TMO
          KAddr = KNumber;                                        //TMO
       inactive = 0;                                              // every valid kernal leaves inactive state
       EEPROM.write(EEPROMAddr+1, inactive);                      // write it to EEPROM
       SwitchKernal();                                            // Switch Kernal Number and reset C64
    }
    else if ((key == 0) && (RestoreKey == 1)) {                   // key "0" switches to kernal #1 and enters inactive state
      KNumber = 1;                                                // inactive means, that the initial key scan timeout is inactive
      EEPROM.write(EEPROMAddr, KNumber);                          // which is useful for catridges, that do not perform a keyboard scan
//TMO:KAddr = KNumber - 1 + KOffset;
      if (KOffset == 0)                                          //TMO
         KAddr = KNumber - 1;                                    //TMO
      else                                                       //TMO
         KAddr = KNumber;                                        //TMO
      inactive = 1;                                               // enter inactive state
      EEPROM.write(EEPROMAddr+1, inactive);                       // write it to EEPROM
//TMO:      Serial.println( "Kernal 1 and scan timeout inactive." );    // send to serial
      SwitchKernal();                                             // Switch Kernal Number and reset C64
    }
    else {
      key = 128;                                                  // reset the key number
    }
    NumPressed = 0;                                               // reset the flag, so the ISR can process key matrix again
  }
  else {
    key = 128;                                                    // reset the key number
  }
  delayMicroseconds( 1000 );                                      // delay 1ms per loop (not calibrated)
}
